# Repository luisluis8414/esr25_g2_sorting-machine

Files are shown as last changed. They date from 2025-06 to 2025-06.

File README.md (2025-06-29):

# esr25_g2_sorting-machine - Medikamenten Sortiermaschine

Dieses Projekt implementiert eine automatisierte Sortiermaschine unter Verwendung des MSP430FR2355. Das System wurde entwickelt, um Objekte (Medikamente) basierend auf ihrer Farbe mithilfe eines Farbsensors und einer servogesteuertern Kippplatform zu sortieren.

# Demo

## Sortiervorgang in Aktion
Sortiervorgang Demo

## Ein paar Bilder
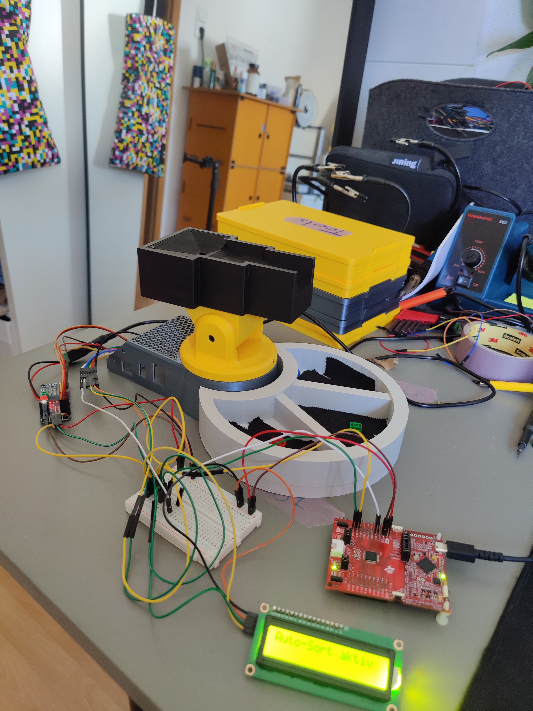
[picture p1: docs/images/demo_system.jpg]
Gesamtsystem
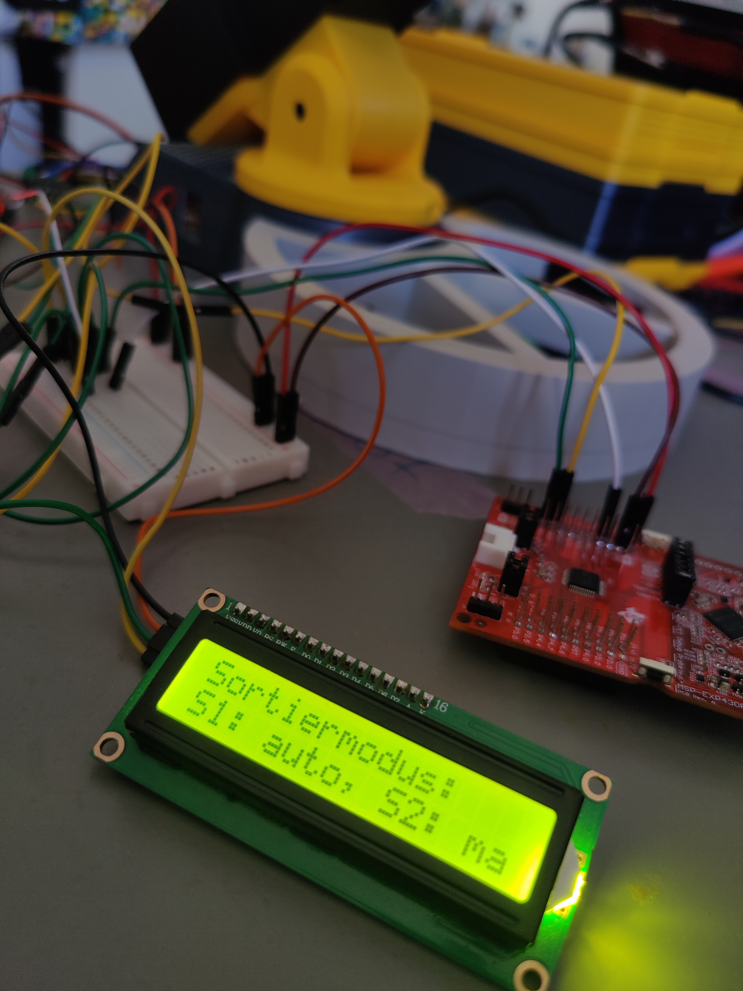
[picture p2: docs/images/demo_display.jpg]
LCD Display
|  |  | Sortiersystem |
|:---:|:---:|:---:|
| *Komplettes System* | *LCD-Display - Hier Auswahl des Sortiermodus* | *Sortierplattform sortiert rote Pille* |

# Systemarchitektur

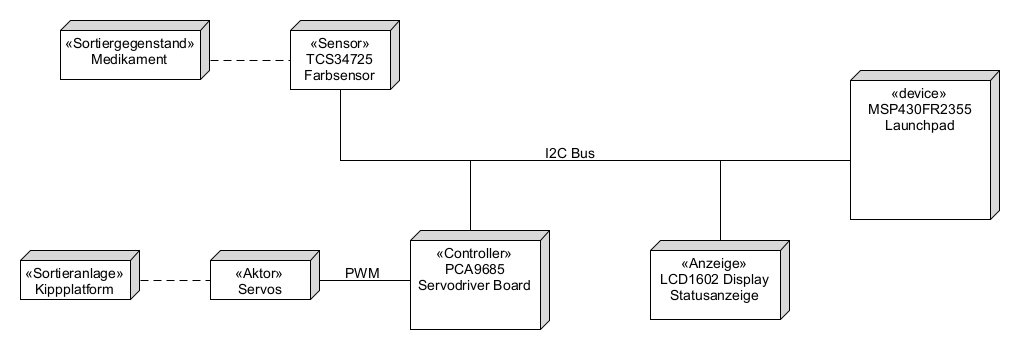
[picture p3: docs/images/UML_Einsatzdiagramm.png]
Systemarchitektur


Das System besteht aus folgenden Hauptkomponenten:

- **MSP430FR2355 Launchpad**: Mikrocontroller
- **TCS34725 Farbsensor**: RGB-Farberkennung zur Objektidentifikation
- **PCA9685 Servotreiber**: PWM-Controller für Servomotoren
- **LCD1602 Display**: Statusanzeige für System-Feedback
- **Servomotoren**: Aktoren für die Sortierplattform

# Hardware-Implementierung

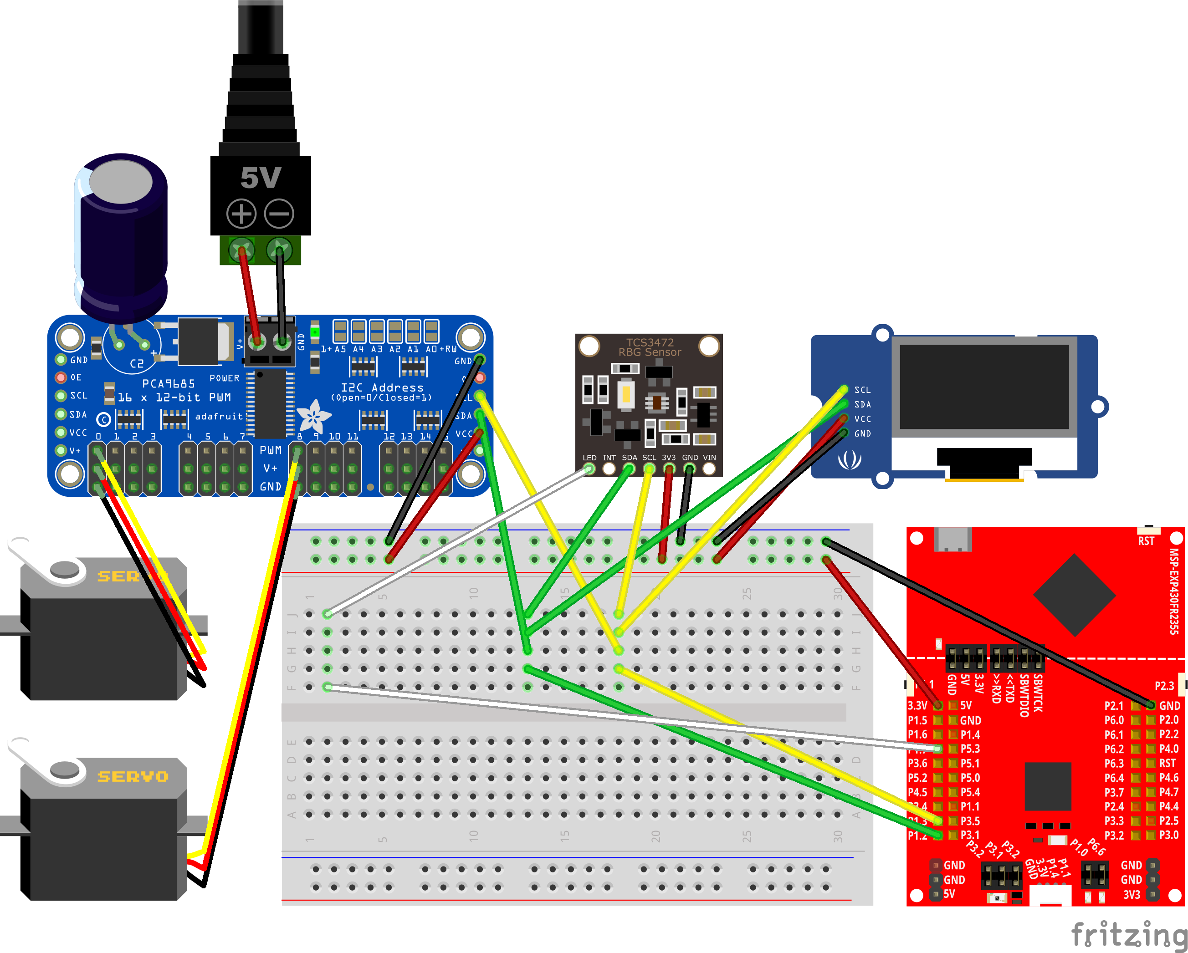
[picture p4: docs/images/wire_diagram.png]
Verdrahtungsplan


## Hauptkomponenten und Verbindungen

- **I2C-Bus-Kommunikation**:
  - Verbindet den Farbsensor (TCS34725)
  - Steuert den Servotreiber (PCA9685)
  - Kommuniziert mit dem LCD-Display (LCD1602)
- **Servo-Plattform**: Mechanischer Sortiermechanismus, gesteuert durch Servomotoren
- **Stromversorgung**: 3.3V-Stromverteilung für alle Komponenten, 5V extra Versorgung für die Sevos

# Mikrocontroller-Peripherie

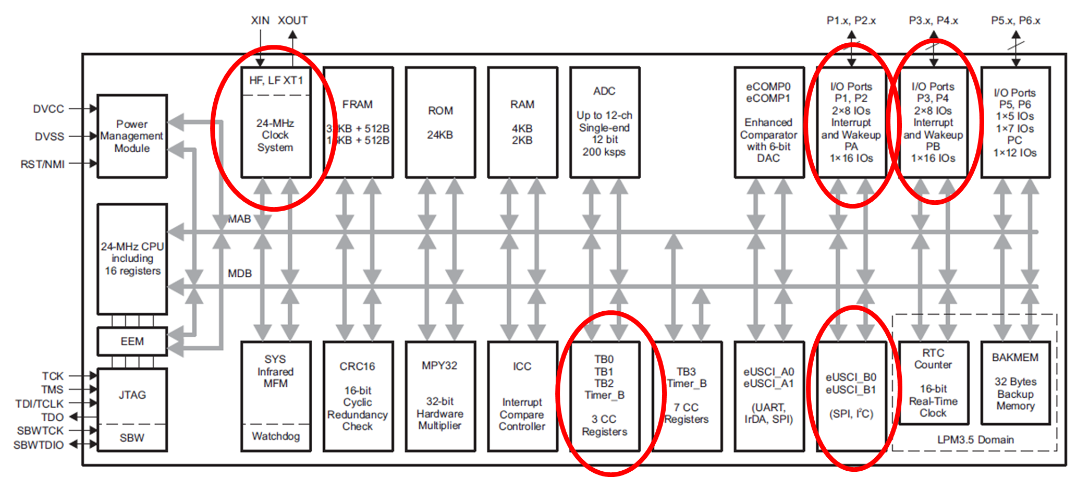
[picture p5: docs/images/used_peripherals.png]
Verwendete Peripherie


Der MSP430FR2355 nutzt folgende wichtige Peripheriekomponenten:

- **I2C-Schnittstelle**: Für die Kommunikation mit TCS, PCA und LCD
- **Timer-Module**: Für Timer, Systemtick und button debouncing
- **GPIO-Ports**: Für allgemeine Ein-/Ausgabesteuerung
- **Taktsystem**: 1MHz Systemtakt

# Projektstruktur

```
esr25_g2_sorting-machine/
├── button/             - Button-Schnittstellenimplementierung
├── I2C/                - I2C-Kommunikationsprotokoll
├── lcd1602_display/    - LCD-Display-Treiber und Manager
├── led/                - LED-Steuerungsimplementierung
├── PCA9685/            - Servotreiber-Controller
├── platform/           - Plattform-Steuerungslogik
├── state_machine/      - Hauptsystem-Zustandsverwaltung
├── TCS34725/           - Farbsensor-Treiber
└── timer/              - Timer-Konfigurationen
```

# Dokumentation generieren

Das Projekt verwendet Doxygen zur Dokumentationsgenerierung. Um die Dokumentation zu erstellen:

1. Stelle sicher, dass [Doxygen](https://www.doxygen.nl/download.html) installiert ist
2. Führe das Script `generate_docs.bat` aus
3. Die generierte Dokumentation ist unter `docs/html/index.html` auffindbar

Das Script wird automatisch:
- Die Doxygen Awesome CSS Theme herunterladen (falls nicht vorhanden)
- Die alte Dokumentation löschen
- Neue Dokumentation generieren
- Die Dokumentation im Browser öffnen

Die Dokumentation enthält:
- Detaillierte API-Beschreibungen
- Funktionsreferenzen
- Architekturdiagramme
- Hardwareverbindungen
- Beispielbilder des Systems

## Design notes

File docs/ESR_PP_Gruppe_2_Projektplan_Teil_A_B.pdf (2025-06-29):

Prof. Dr. rer. biol. hum. Sven Steddin, Medizinisch-Technische Informatik
Hochschule Reutlingen, Alteburgstraße 150, 72762 Reutlingen, www.reutlingen-university.de,
T. +49 (0)7121 271-4011, sven.steddin@reutlingen-university.de

Sortiermaschine mit dem MSP430.

Gruppe
(Bez. aus RELAX)

Gruppenmitglieder (Namen)

ESR__PP_Gruppe_2 Raach, Qunaku, Wehrberger

## Inhalt

Festlegung des bestimmungsgemäßen Gebrauchs (Produktvision /

Nutzungsanforderungen zu NS02: Auslesen des aktuellen Füllzustands der

S2025 – Eingebettete Systeme und Robotik – Projektbeschreibung Vorlage Ver.2 (23.05.2025)

# Aufbau eines Medikamentensortierers

## Teil A (Analysephase): Projektbeschreibung

„Kein Projekt ohne Angabe eines Ziels!“

## Beschreibung des Kontextes der Entwicklung / Motivation

Kontextszenarien
KS01: Sortierung von Medikamenten (Pillen) für Menschen mit Farbblindheit.

Medikamente werden heutzutage immer noch anhand ihrer Farbe unterschieden, insbesondere bei Pillen und Tabletten. Dies erleichtert Patienten sowie Pflegepersonal die schnelle Identifikation und Unterscheidung verschiedener Präparate. Farben dienen oft als visuelle Orientierungshilfe, um Verwechslungen zu vermeiden und die korrekte Einnahme sicherzustellen.

KS02: Sortierung und Zählung von Medikamenten (Pillen) in Apotheken und Pflege

In Pflegeeinrichtungen und Apotheken spielt die manuelle Sortierung und Zählung von Medikamenten eine zentrale Rolle im täglichen Ablauf. Medikamentenbestände müssen regelmäßig überprüft, korrekt zugeordnet und für Patienten oder Kunden bereitgestellt werden. Dabei wird großer Wert auf eine strukturierte Organisation gelegt, um sicherzustellen, dass die richtigen Medikamente zur richtigen Zeit verfügbar sind.

KS02: Verwaltung von Medikamenten

Senioren nehmen oft täglich mehrere Medikamente ein und müssen dabei auf eine strikte Medikamentenverwaltung achten, um eine kontinuierliche Versorgung sicherzustellen. Oft sind Angehörige, Pflegekräfte oder Apotheken unterstützend tätig, um den Überblick über Vorräte und Einnahmezeiten zu erleichtern.

## Festgestellte Mängel (Pain Points)

PP01: Zu bemängeln ist, dass Medikamente oft über ihre Farbe unterschieden werden, was für Menschen mit Farbblindheit ein Risiko von Einnahmefehlern sein kann und oft die Selbstständigkeit einschränkt.

PP02: Zu bemängeln ist, dass Senioren sich oft schwertun, selbst einen Überblick über die Anzahl ihrer übrigen Medikamente zu bewahren.

PP03: Zu bemängeln ist, dass das manuelle Sortieren von Medikamenten in Apotheken und Pflegeeinrichtungen sehr Zeit aufwändig ist.

## Festlegung der Zweckbestimmung des zu entwickelnden Systems

ZB01: Die Entwicklung soll dazu dienen, Medikamente/Pillen automatisch anhand der Farbe zu sortieren. (PP01)

ZB02: Die Entwicklung soll dazu dienen, die Anzahl an unterschiedlichen Pillen zu zählen und wiederzugeben. (PP02)

ZB03: Die Entwicklung soll dazu dienen, Apotheken- und Pflegepersonal das Sortieren und Zählen von Pillen zu vereinfachen. (PP03)

## Festlegung des bestimmungsgemäßen Gebrauchs (Produktvision / Nutzungsszenarien)

NS01: Sortierung von Pillen
Umgesetzte Zweckbestimmungen

ZB01, ZB02, ZB03
Vorbedingungen
1. Das Sortiersystem liegt auf einer stabilen Ebene
2. Die Pillen unterscheiden sich in den Farben Rot, Grün und Blau

Nutzungsvorgang

1. Der Anwender bzw. das Bedienpersonal startet das Sortiersystem und wirft in langsamen Abständen die Pillen einzeln in den Eingang des Sortiersystems.
2. Das Sortiersystem sortiert die Pille innerhalb des Systems und erhöht die auf dem Display angezeigte Menge je Farbe.
3. Der Anwender bzw. das Bedienpersonal führt diesen Vorgang durch, bis alle Pillen sortiert sind

Nachbedingungen

- Die Pillen können aus dem System entnommen werden

NS02: Erfassung der Gesamtanzahl der bislang sortierten Pillen, inklusive farblicher Aufschlüsselung der Stückzahlen.
Umgesetzte Zweckbestimmungen

ZB02

Vorbedingungen

- System ist deaktiviert, und nicht am Sortieren.

Nutzungsvorgang

1. Das Bedienpersonal aktiviert das Füllzustands-Display.
2. Das Display zeigt wie viele Pillen bisher sortiert wurden. Zusätzlich zeigt es jeweils die Anzahl pro Farbe an.
3. Der Anwendende liest den aktuellen Füllzustand der Sortiermaschinen-Behälter aus.

Nachbedingungen

- Display geht in den vorherigen Zustand also, deaktiviert oder in die Anzeige des Displays des Bereitschaftsmodus.

## Stakeholder

Stakeholder | Benutzerrolle
Patienten mit Farbsehstörungen | Person, welche selbständig ihre Medikamente identifizieren und unterscheiden will.
Senioren mit regelmäßiger Medikamentenein- nahme | Person, die ihren Medikamentenbestand leicht kontrollieren will.

Pfegepersonal in
Einrichtungen

Person, die schnell Medikamente Sortieren und eine Übersicht über Vorräte will

Bedienpersonal | Patienten, Senioren und Pflegepersonal

## Festlegung der Nutzungsanforderungen (funktionale Anforderungen)

## Nutzungsanforderungen zu NS01: Sortierung von Pillen

# | Nutzungsanforderung | Definition of Done

NA001 | Als Bedienpersonal der Sortiermaschine möchte ich die Sortierung einer Pille starten können, damit ich nicht aus Versehen eine Pille sortieren lasse oder etwas Falsches darin sortiere. | Es ist eine Eingabefunktion vorhanden, die den Sortierprozess der Sortiermaschine initialisiert.
NA002 | Als Bedienpersonal der Sortiermaschine möchte ich die Möglichkeit haben farbige Pillen (rot, grün oder blau) einzeln hinzuzufügen, damit sie sortiert werden können.

Es ist eine Form von Oberfläche vorhanden, worauf die zu sortierende farbige Pille (rot, blau oder grün) liegen kann, sodass sie sortiert werden kann.

NA003 Als Bedienpersonal der Sortiermaschine möchte ich sehen können, welche Zuordnung passiert ist, um sicherzustellen, dass die Zuordnung korrekt ist.

Es ist eine visuelle Anzeige vorhanden, die dem Bedienpersonal aufzeigt, welche Zuordnung für die Pille erfolgt ist.

NA004 Als Bedienpersonal der Sortiermaschine möchte ich eine eindeutige Stelle erkennen können, an der die Pille zum Sortierprozess eingegeben werden kann, um sie an die richtige Stelle zu legen.

Es besteht eine Eingabefläche für die Pillen an der Sortiermaschine.

NA005 Als Bedienpersonal der Sortiermaschine möchte ich erkennen können, ob die Sortierung gestartet wurde, um zu wissen, wie der Zustand der Sortiermaschine ist.

Es gibt ein visuelles Feedback an das Bedienpersonal bei Beginn des Sortierprozesses.

NA006 Als Bedienpersonal der Sortiermaschine möchte ich die Möglichkeit haben zu sehen, ob ich eine Pille sortieren lassen kann, um zu wissen, wann ich die nächste Pille nachlegen kann.

Es ist eine visuelle Anzeige vorhanden, die dem Bedienpersonal aufzeigt, dass die Sortiermaschine sortierbereit ist.

NA007 Als Bedienpersonal der Sortiermaschine möchte ich die Möglichkeit zu sehen, ob der Prozess der Sortierung beendet ist, um den Sortierungszustand zu kennen.

Es ist eine visuelle Anzeige vorhanden, die dem Bedienpersonal aufzeigt, dass der Sortierprozess beendet wurde.

NA008 Als Bedienpersonal der Sortiermaschine möchte ich, dass für jede Pillenfarbe (rot, grün, blau) ein separater, zugeordneter Behälter vorhanden ist, damit die Pillen nach der Sortierung eindeutig und sauber getrennt gesammelt werden können.

Es sind Behälter am System vorhanden, die das System erreichen kann, um Pillen zu sammeln.

NA009 Als Bedienpersonal der Sortiermaschine möchte ich, dass die erkannte Pille dem farblich passenden Behälter zugeführt wird, damit sie sortiert bleibt.

Es ist ein Mechanismus vorhanden, der, die auf der Oberfläche liegende, Pille in den korrekten Behälter zuführt.

NA0010 Als Bedienpersonal der Sortiermaschine möchte ich, dass das System die Farbe (rot, grün

Es ist ein Mechanismus mit einer Sensorik vorhanden, der rote, blaue oder blau) jeder eingeführten Pille erkennt und zuweist, damit die Pillen unterschieden und sortiert werden können.

und grüne Pillen voneinander unterscheiden und zuweisen kann.

NA0011 Als Bedienpersonal der Sortiermaschine, möchte ich die Sortiermaschine aktivieren können, damit sie nur bei Bedarf läuft.

Es ist eine Eingabefunktion vorhanden, die die Sortiermaschine aktiviert.

## Nutzungsanforderungen zu NS02: Erfassung der Gesamtanzahl der bislang sortierten Pillen, inklusive farblicher Aufschlüsselung der

Stückzahlen.

NA011 Als Bedienpersonal der Sortiermaschine, möchte ich sehen können wie viele Pillen bereits sortiert worden (inklusive der Anzahl pro Farbe) sind, um zu wissen, wie die Verteilung der Pillen ist und wie viele Pillen bisher sortiert worden sind.

Es ist eine visuelle Anzeige vorhanden, die dem Anwender die Gesamtanzahl der bislang sortierten Pillen, inklusive farblicher Aufschlüsselung der Stückzahlen anzeigt.

NA012 Als Bedienpersonal der Sortiermaschine möchte ich die Möglichkeit haben die Zähler, der sortierten Pillen, anzuzeigen, um den Zustand bei Bedarf zu sehen.

Es gibt ein Eingabegerät, dass dem Anwender ermöglicht eine Anzeige des Füllstands zu aktivieren.

NA013 Als Bedienpersonal der Sortiermaschine möchte ich die Möglichkeit haben, den Counter der bisher sortierten Pillen zurückzusetzen.

Es gibt ein Eingabegerät, dass dem Anwender ermöglicht den Counter der Pillen zurückzusetzen.

## Festlegung der Systemanforderungen

## Funktionale Anforderungen

# | Systemanforderung funktional (SAF)

Bestimmungsgröße

Testverfahren

SAF-01 /
NA001

Das System muss ein mechanisches Bedienelement besitzen, um einen Sortierprozess initialisieren zu können.

Betätigung des
Bedienelements

Der Sortierprozess lässt sich über eine Taste starten.

Pass:
Der Sortierprozess wird geeignet gestartet.

SAF-02 /
NA002

Das System muss eine Oberfläche besitzen, auf der eine farbige Pille liegen kann, damit sie sortiert werden kann.

Vorhandensein der
Oberfläche

Auf die Oberfläche wird eine farbige Pille gelegt und ein Sortierprozess wird initialisiert und durchgeführt.

Pass:
Sortierprozess der Pille läuft vollständig und ohne
Beeinträchtigung, durch die Oberfläche ab und Pille liegt vor der Beförderung zum Behälter auf der Oberfläche.

SAF-03 /
NA003

Das System muss eine visuelle Ausgabe/ Display besitzen, um die Zuordnung einer erkannten Pille darzustellen.

Erkannte Farbe | Der Sortierprozess des Systems wird einzeln mit einer roten, blauen und grünen Pille ausgeführt. Pass: Bei jeder Pille wird die jeweils richtige Farbe zu einem geeigneten Zeitpunkt dargestellt.

SAF-04/
NA004

Das System muss eine Eingabefläche für eine farbige Pille besitzen, damit die Sortierung überhaupt stattfinden kann.

Vorhandensein der
Eingabefläche

Es wird eine Pille auf die Oberfläche gelegt.

Pass:
Nach der Auflage der Pille auf die Oberfläche ist ein Sortierprozess startbar.

SAF-05 /
NA005

Das System muss eine visuelle Anzeige besitzen, um darstellen zu können, dass der Sortierungsprozess begonnen hat.

Systemstatus | Es wird ein Sortierprozess nach Auflage einer Pille initialisiert. Pass: Das Display zeigt zu einem geeigneten Zeitpunkt den Beginn der Sortierung an. .

SAF-06 /
NA006

Das System muss eine visuelle Anzeige besitzen, um darstellen zu können, dass der Sortierungsprozess bereit ist.

Systemstatus | Die Sortiermaschine wird in den Bereitschaftsmodus gesetzt. Pass:
a) Nach Aktivierung der
| Sortiermaschine per Tastendruck zeigt Display geeignet an, dass sie bereit ist.
b) Nach erfolgreich beendetem
| Sortierungsprozess der Sortiermaschine zeigt Display geeignet an, dass sie bereit ist.

SAF-07 /
NA007

Das System muss eine visuelle Anzeige besitzen, um darzustellen zu können, ob der Prozess der Sortierung beendet ist.

Systemstatus | Es wird ein Sortierprozess nach Auflage einer Pille initialisiert. Pass: Das Display zeigt zu einem geeigneten Zeitpunkt das Ende der Sortierung an. .

SAF-08/
NA008

Das System muss für jede mögliche Zuordnungsfarbe einen für das System erreichbaren Behälter besitzen, in denen Pillen aufbewahrt werden können, damit nach der Sortierung die Pillen getrennt gesammelt werden können.

Farben | Der Sortierprozess des Systems wird einzeln mit einer roten, blauen und grünen Pille ausgeführt. Pass: Für jede Pille gibt es einen eigenen Behälter und nach jedem Sortierungsprozess ist Pille in entsprechendem Behälter.

SAF-09/
NA009

Das System muss einen Mechanismus besitzen, der eine erkannte Pille automatisch in den zugeordneten Behälter befördert, um die Sortierung zu persistieren.

Farbzuordnung | Der Sortierprozess des Systems wird einzeln mit einer roten, blauen und grünen Pille ausgeführt. Pass: Jede Pille landet in ihrem geeigneten Behälter, sobald die Erkennung und Zuweisung der Pille erfolgt ist.

SAF-010/
NA0010

Das System muss einen Mechanismus besitzen, die Farben …

a) Rot,
b) Blau oder
c) Grün
einer Pille zu unterscheiden und sie entsprechend zuzuweisen, um die Sortierungsfähigkeit zu gewährleisten.

Farbdaten des Sensors Der Sortierprozess des Systems wird einzeln mit einer roten, blauen und grünen Pille ausgeführt. Pass: Für jede Pille wird die geeignete Farbe erkannt und zugewiesen und Display zeigt geeignete Farbe an und Pille landet in richtigem Behälter.

SAF-011/
NA0011

Das System muss ein mechanisches Bedienelement besitzen, um die Sortiermaschine zu aktivieren.

Betätigung des
Bedienelements

Der Sortiermaschine lässt sich über eine Taste starten.

Pass:
Die Sortiermaschine startet und geht in einen geeigneten
Bereitschaftsmodus.

SAF-012/
NA011

Das System muss ein Display besitzen, dass die aktuellen Zähler der Sortiermaschine darstellt, um dem Bedienpersonal die Anzahl der bisher sortierten Pillen anzuzeigen.

Anzahl der Pillen | Das Display der Sortiermaschine wird per Tastendruck aktiviert.
| Pass: Das Display zeigt die korrekten Zähler der sortierten Pillen der Sortiermaschine an.

SAF-013/
NA012

Das System muss ein mechanisches Bedienelement besitzen, um das Füllstand-Display aktivieren zu können.

Betätigung des
Bedienelements

Das Display lässt sich über eine Taste starten.

Pass:
Das Display geht an und zeigt Informationen an.

SAF-014/
NA011

Das System muss in der Lage sein, die bisher sortierten Pillen zu zählen, um die Anzahl der bisher sortierten Pillen zu erfassen (Gesamtzahl und Anzahl pro Farbe).

Pille | Der Sortierprozess des Systems wird einzeln mit einer roten, blauen und grünen Pille ausgeführt. Pass: Für jede Pillenfarbe wurde eine Pille gezählt und angezeigt. Und nach jedem Sortierungsprozess ist die Gesamtzahl der Pillen, um eins inkrementiert.

SAF-015/
NA011

Das System muss ein mechanisches Bedienelement besitzen, um die Zähler der bisher sortierten Pillen zurückzusetzen, um die Anzahl von Neuem erfassen zu können.

Betätigung des Bedienelements | Der Sortierprozess des Systems wird einzeln mit einer roten, blauen und grünen Pille ausgeführt. Pass: Nach dem Betätigen des mechanischen Bedienelements zeigen die Zähler bei der Gesamtzahl und Zahl pro Farbe jeweils null an, nachdem die Anzeige dafür aktiviert wurde.

## Nicht funktionale Anforderungen

# Systemanforderung nicht funktional (NFA)

Testverfahren
(Definition of Done)

NFA-01

Das System muss mit dem Launchpad MSP430FR2355 umgesetzt werden

Sichtkontrolle: Prüfung der Produktbezeichnung auf der Systemplatine

NFA-02

Das System muss mit dem CCS, Version 12.0 oder höher erstellt werden

Kontrolle der Version des Entwicklungssystems auf dem Entwicklungsrechner:
a) Version muss der Anforderung entsprechen
b) Programm muss sich fehlerfrei übersetzen und auf das Zielsystem übertragen lassen
NFA-03

Das System muss ein Hauptprogramm besitzen, welches ein state machine design implementiert (Mealy Automat): Beispiel wird in der Vorlesung gezeigt.

Code review

NFA-04

Das System darf, von kleinen Ausnahmen abgesehen, kein busy waiting betreiben, d.h. es müssen die Low Power Modes des Prozessors genutzt werden. Diese Anforderung hat oberste Priorität!

Review der main loop des Programmes

NFA-100

Das System muss mit Hilfe von Doxygen dokumentiert werden

Aufruf des zum Projekt gehörenden Doxygen Scripts zur Erzeugung der vollständigen Dokumentation im HTML Format -- > Es muss ein vollständig über Doxygen generiertes manual erzeugt werden.
NFA-101

Die Software und die Dokumentation müssen unter Versionskontrolle stehen. Hierfür ist GIT einzusetzen.

Kontrolle der Struktur des zugehörigen Repository über den TortoiseGIT Repository Explorer oder über ein vergleichbares Tool zur Inspektion des Repository

NFA-102

Alle Dokumente zur Dokumentation der Software sollen zusammen mit dem Source Code im Stammverzeichnis des CCS Projekts im Ordner Docs abgelegt werden. Es wird eine Projektvorlage zur Verfügung gestellt, die diese Struktur bereits besitzt.

Kontrolle der Struktur des Docs-Verzeichnisses im Projektverzeichnis:

NFA-103

Das System muss in einer 3 Minuten Demo vollständig präsentierbar sein

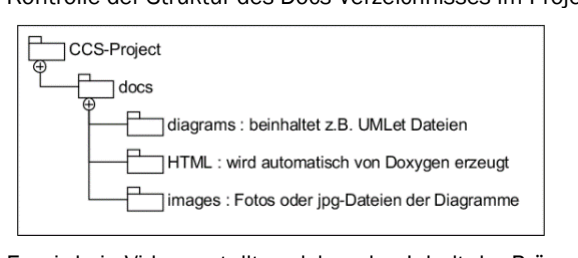
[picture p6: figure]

Es wird ein Video erstellt, welches den Inhalt der Präsentation wiedergibt und das nachweislich nicht länger als 3 Minuten dauert.

NFA-104

Das System muss über eine 3V Batterie im stand-alone Modus betrieben werden können (, getrennt von den Servomotoren).

System wird mit 3V Lithium Knopfzelle verbunden. ICD-Bereich wird über Jumper als Verbraucher vom MC-Bereich des Launchpads getrennt, damit der Verbrauch des Systems möglichst gering ist. System muss sich starten lassen.

NFA-105

Die Sortiermaschine muss nach der Aktivierung oder einer Sortierung nach 30 Sekunden automatisch beendet werden, so dass die Messsensorik und das Display möglichst wenig Strom verbrauchen.

Die Versorgungsspannung an der Sensorik und am Display muss nach Ablauf der Messdauer abgeschaltet sein.

NFA-106

Der Sortierprozess muss nach spätestens fünf Sekunden terminiert sein, so dass das Bedienpersonal möglichst schnell Pillen sortieren lassen kann.

Sortierungsprozess der Sortiermaschine muss nach Ablauf der Messdauer fertiggestellt sein und Sortiermaschine muss im Bereitschaftsmodus sein.

NFA-106

Das Display der Sortiermaschine muss nach der Aktivierung (per Aktivierung der Sortiermaschine oder per Aktivierung des Displays) oder einer Sortierung nach 30 Sekunden automatisch beendet werden, so dass das Display möglichst wenig Strom verbraucht.

Die Versorgungsspannung am Display muss nach Ablauf der Messdauer abgeschaltet sein.

NFA-107

Das Display der Sortiermaschine muss fünf Sekunden nach der Aktivierung ausgehen, falls es nur aktiviert wurde, um die Gesamtanzahl der bislang sortierten Pillen, inklusive farblicher
Aufschlüsselung der Stückzahlen anzuzeigen. Das soll getan werden, so dass das Display möglichst wenig Strom verbraucht.

Die Versorgungsspannung am Display muss nach Ablauf der Messdauer abgeschaltet sein.

## Zugesicherte Leistungsmerkmale

# | Zugesichertes

| Leistungsmerkmal (ZLM)

Bestimmungsgröße

Testverfahren
(Definition of Done)

ZGL-01 Rutschfeste Auflageoberfläche für eine Pillen.

Material | Die auf der Auflageoberfläche aufliegende
Pille muss bei einer waagrechten Fläche auf der Stelle liegen bleiben.

ZGL-02 Energieversorgung:
Batteriebetriebenes System

Versorgungsspannung:

Betrieb muss bei 2,6V
… 3V Versorgungsspannung möglich sein

Das System muss bei 2,6 V und bei 3V Versorgungsspannung funktionstüchtig sein.

ZGL-03 Batterielebensdauer: Bisher unklar

Durchschnittliche
Stromaufnahme des
Systems während der
Sortierung: Bisher
unklar

Bisher unklar

ZGL-04 Betrieb bei normalen Raumumgebungsbedingungen möglich: Temperatur: 20°C +/-10°C Feuchte: 60% +/- 20%

Temperatur und
Feuchte

System muss bei normalen
Raumbedingungen (20°C / 60% Feuchte) funktionstüchtig sein. Auf eine Prüfung der Grenzwerte wird verzichtet, da bei den angegebenen Werten keine Probleme zu erwarten sind.

ZGL-05 Sortierung ist mit einer >= 95% Wahrscheinlichkeit erfolgreich. (unklar)

Farbe der eingelegten
Pille

Farbsensor-Funktionalität mit Unit-Test gewährleisten.

System muss bei 100 eingegebenen in möglichst zufälliger Reihenfolge mindestens 95 Pillen richtig sortieren.

ZGL-06 Sortierungsprozess erfolgt in <= 5 Sekunden (unklar)

Pille | System muss bei z.B. 100 eingegebenen
Pillen unter 5 Sekunden bei allen Sortierungen sein.

## Teil B: Designphase

## Blackbox Betrachtung: Blockdiagramm

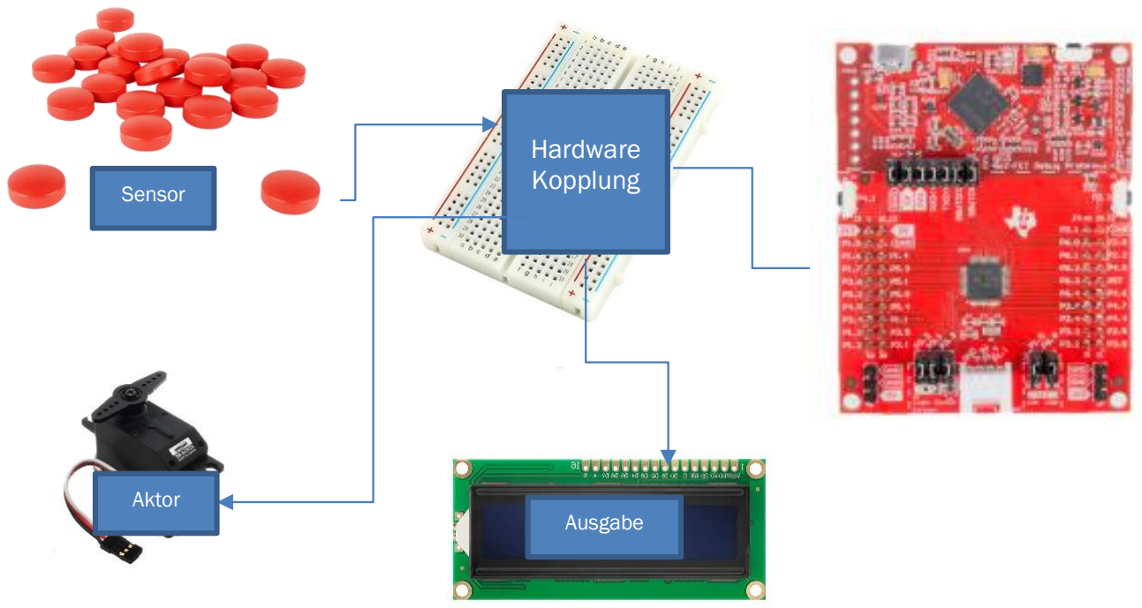
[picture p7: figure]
Hardware Kopplung Sensor; Aktor; Ausgabe

## Systemarchitektur

## Systemdesign: UML Einsatzdiagramm

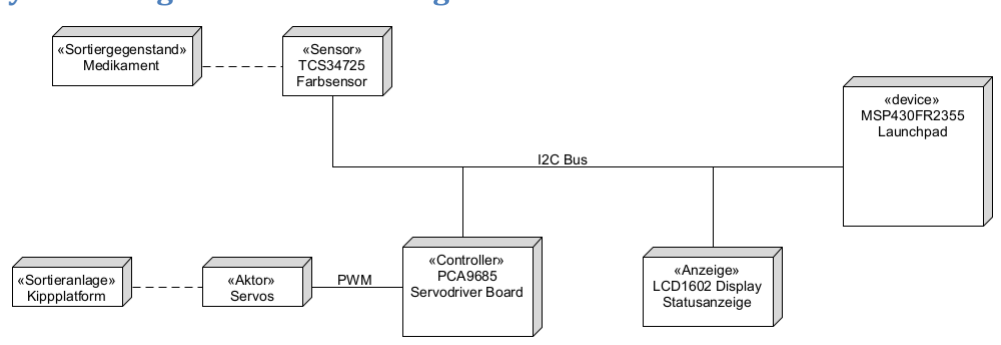
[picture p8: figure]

## Hardware-Design

Erforderliche Sensoren (Input)
# | Sensorbezeichnung | zu erfassende Parameter

Funktion

1

TCS34725 RGB Farb Sensor | RGB-Werte | Der Sensor misst die Farbkomponenten des einfallenden Lichts mit Hilfe integrierter Farbfilter und eines ADCs. Die digitalisierten R, G, B und Clear-Werte werden über den I²C- Bus bereitgestellt. Eine interne LED ermöglicht gleichmäßige Ausleuchtung des Objekts (z. B. Pille)
2 | Taster
Launchpad Taster S2: P2.3 | | Display mit Füllstand einschalten
3 | Taster
Launchpad Taster S1: P4.1

System einschalten

4 | Taster Reset: fest verdrahtet | - | Reset des Systems

Erforderliche Aktoren (Output)
# | Sensorbezeichnung | Ausgabegröße | Zweck

1 | PCA9685/ 2x Servos | PWM | Ansteuerung der Sortiermechanik (Plattformpositionen)
2 | LCD1602 Display mit dem PCF8574A Modul | Textausgabe | Anzeige von Farbwerten, Zuordnung, Counter o. ä.
3 | LED1 (rot) MSP430 Launchpad | On / Off | Zustandsanzeige

Erforderliche Schnittstellen (Kommunikation)
# | Schnittstelle | Betriebsparameter | Zweck

1 | I²C | Anschluss LCD1602,
| | TCS34725 Farbsensor,
| | PCA9685 Servodriver Board

Übermittlung der Steuerbefehle und der Daten die für das Display, Farbsensor und Servodriverboard benötigt werden.

Festlegung der verwendeten Peripheral Blocks

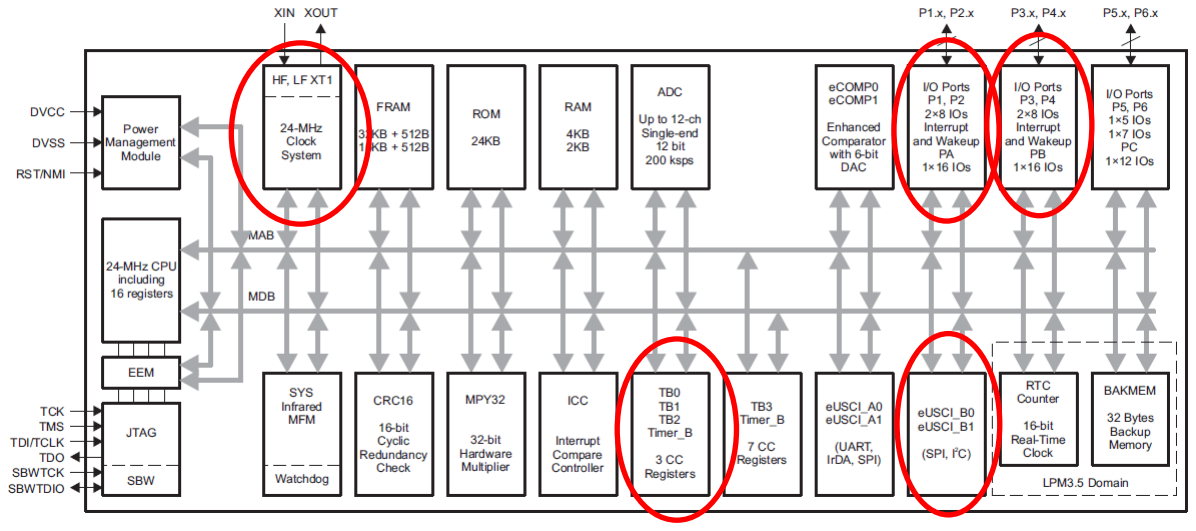
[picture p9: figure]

Block | Einsatzzweck
24 MHz Clock System | Bereitstellung MClk und SMClk (ca. 1 MHz) und AClk, synchronisiert mit 32768 Hz Uhrenquarz
P1 | P1.0: LED1, P1.2: SDA, P1.3: SCL, P1.4: INT (Farbsensor), P1.1: LED (Farbsensor)
P2 | P2.3: Taster S2
P4 | P4.1: Taster S1
Timer0_B3 | Zeitsteuerung der state machine
eUSCI_B0 | I²C-Kommunikation mit Display, Farbsensor und Servodriverboard

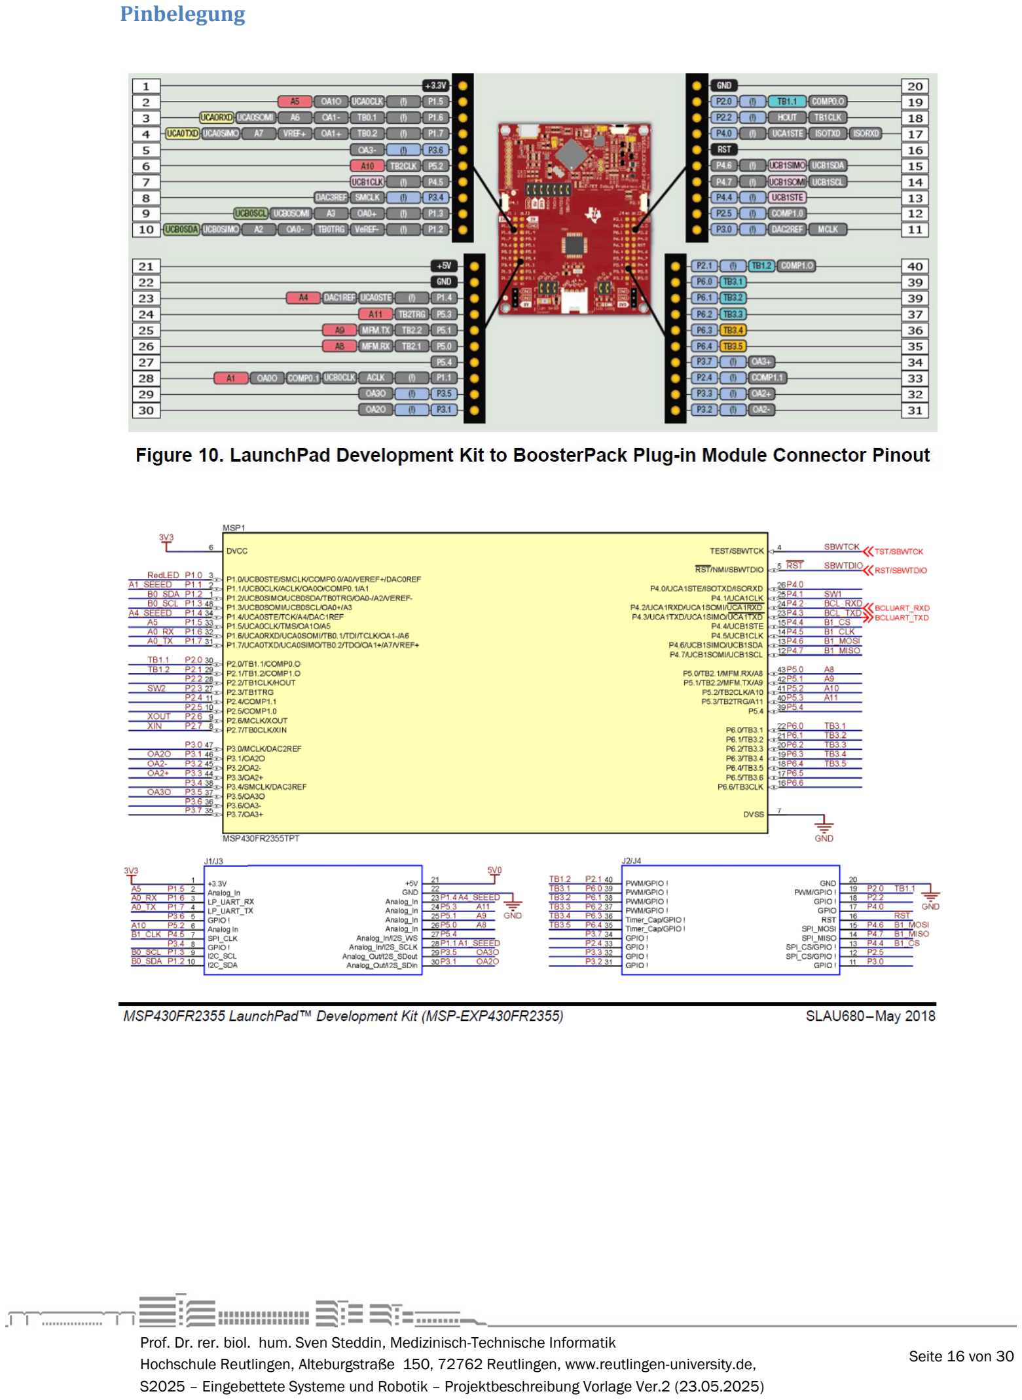
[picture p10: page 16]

Pinbelegung

Pin | Peripherie-block | Pin Name | IC-Pin | LP-Pin | Signal | Zweck
1 | Spannungsver-sorgung | DVCC | | | 3,3V | I²C Anschluss Versorgungsspannung

2
3
4
5
6
7
8
9 | eUSCI_B0 | P1.3 | 48 | 9 | SCL | I²C-Clockleitung
10 | eUSCI_B0 | P1.2 | 1 | 10 | SDA | I²C-Datenleitung
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
20 | Masse | GND | | 20 | - | I²C Anschluss Masseverbindung

21
22
23 | PORT 1 | P1.4 | 34 | 23 | LED | Ansteuerung LED TCS3472
24
25
26
27
28 | PORT 1 | P1.1 | 2 | 28 | INT | Interruptleitung TCS3472
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
Blockschaltbild / Verdrahtungsplan

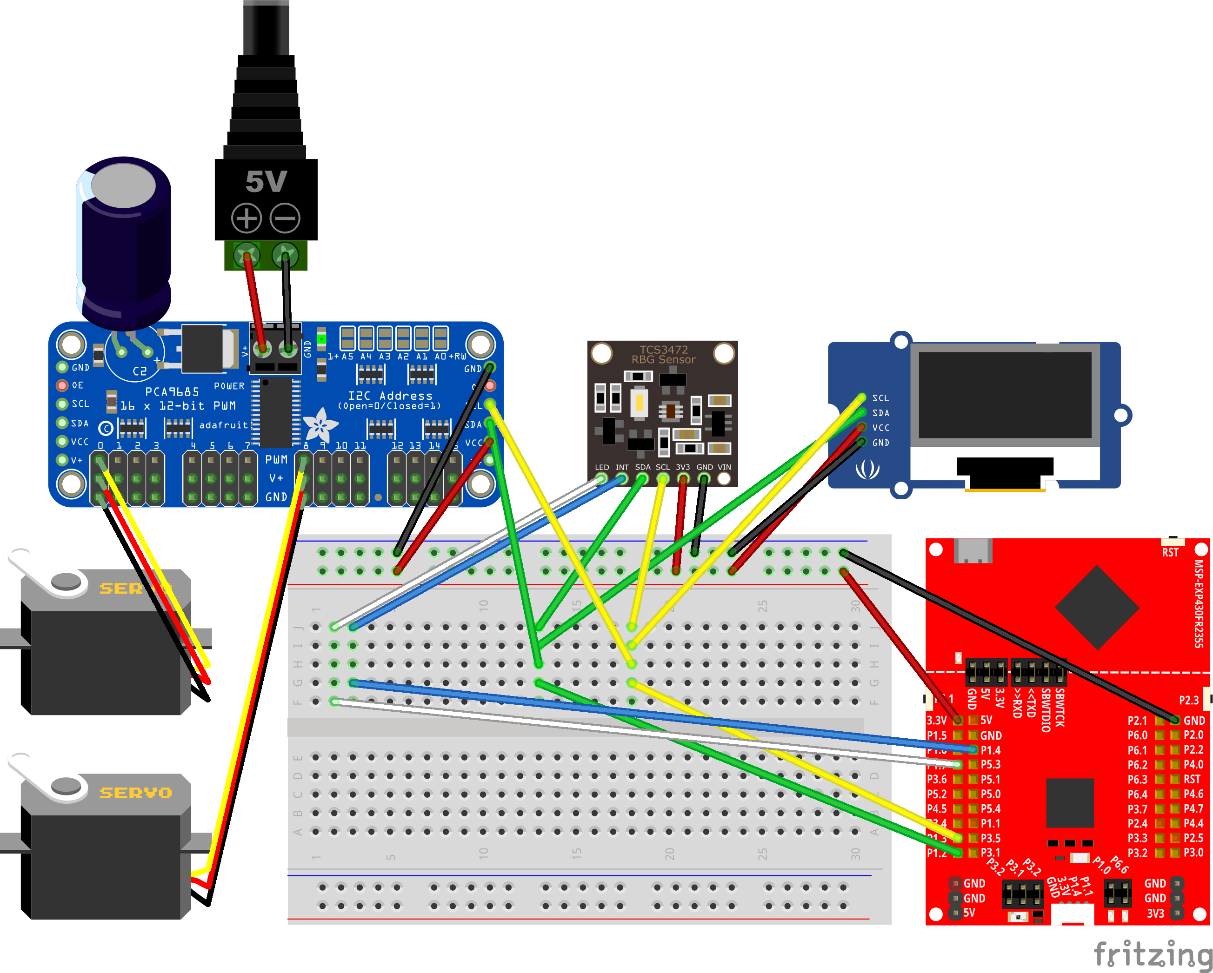
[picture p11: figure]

## Aufwandsschätzung

Peripheral | Function-points | Einsatzzweck
TCS34725 | 4 | Erfassung der Farbe / Lichtschranke
PCA9685/ 2 Servos | 3 | Steuerung der Servos / Kippplattform
LCD1602/ PCF8574A | 4 | Textanzeige, Zähler der sortierten Pillen,
S1/S2 | 2 | System aufwecken, Modus wählen, Start der Messung
LED1 rot/ LED grün | 2 | Statusanzeige
Summe FPs | 15

## Teil C – Implementierung / Umsetzung

## Software-Design

Softwarearchitektur: Use Case Diagramm(e)
[Bla: Umsetzung der Nutzungsszenarien aus Sicht des Systems: welche Funktionen bietet das System an, um die beschriebenen user stories umsetzen zu können? Zu einem Übersichtsdiagramm zugehörig können noch <<includes>> und <<extends>> Beziehungen definiert werden.]

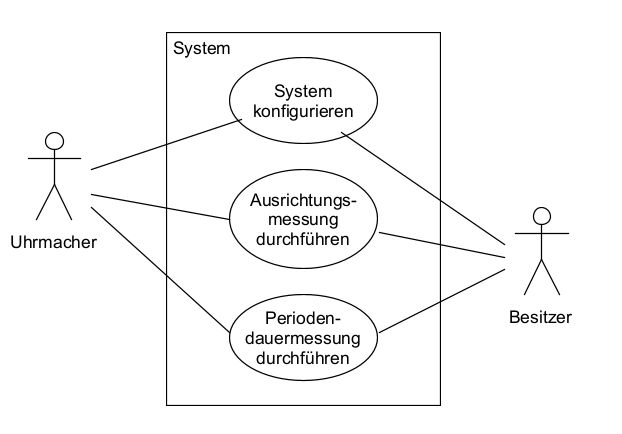
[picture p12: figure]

Softwarearchitektur: Strukturdiagramm
[Bla: Das Softwarestrukturdiagramm zeigt die Dekomposition der Software Komponenten. Hierbei ist darauf zu achten, dass der HAL so ausgelegt wird, dass das API (Festlegung der nach außen sichtbaren Daten und Funktionen) keine Abhängigkeiten zur Applikationsebene besitzt und daher die Treiberfunktionen in jeder beliebigen Applikation verwendbar sind.]

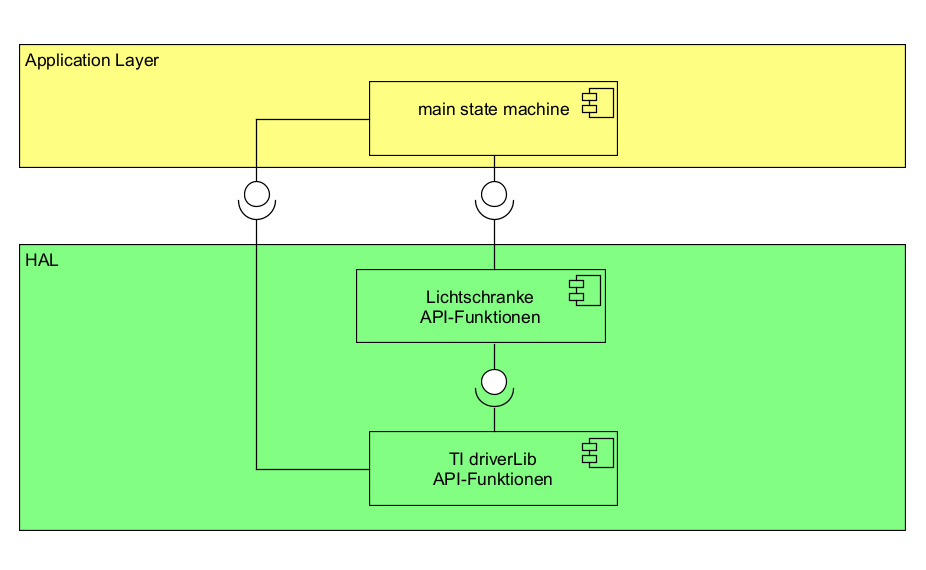
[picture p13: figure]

Aktivitätsdiagramm(e) /state Diagramme
[Bla: Darstellung des Aufbaus der mainloop und der wichtigen ISRs]

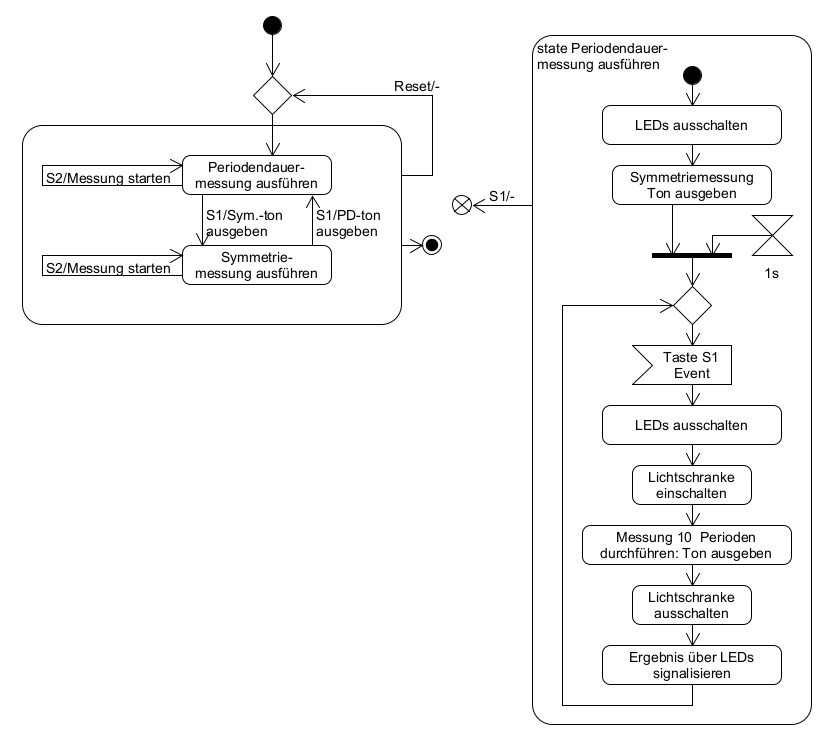
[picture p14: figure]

Abbildung 1 : links - state diagram; rechts: activity diagram

Activity Diagramm für state Symmetriemessung ausführen wie bei state Periodendauermessung ausführen; die beiden States unterscheiden sich nur bzgl. des Algorithmus‘ zur Ergebnisberechnung.

## Softwareanforderungen

[Bla: Jede Systemanforderung muss in mindestens einer Softwareanforderung berücksichtigt werden]

Entfällt im Rahmen des embedded Projekts … ☺

## Softwareentwicklungsplan

Release | Beschreibung der Funktionalität / des Ziels | geplanter
| | Zeitpunkt der
| | Fertigstellung
0.1 | Implementierung der API für die RGB-Farberkennung
- Unterscheidung von Farben rot, grün und blau
| Implementierung der API zur Servoansteuerung
- Rotation der Servos von 0 bis 180 Grad
| Implementierung der Textanzeige auf LCD Display
| - | 16.06
0.2 | Implementierung der on/off Steuerung der Lichtschranke
- Zeitliches An-/Ausschalten des Sensors

[bla]

0.3 | Implementierung Programmlogik
- Definition des Programmablaufs
- Implementierung der main state machine
1.0 | Optimierung und Reifmachung für Deployment | [bla]

## Konfigurationsmanagementplan

- Die Versionsverwaltung erfolgt mittels EGIT über das CCS
- Es gibt einen master branch, der mit einem zentralen Repository abgeglichen wird
- Lokale Entwicklungen werden auf branches im lokalen Repository durchgeführt. Die geprüften Module werden auf den master-Branch überspielt. Dieser wird mit
| dem zentralen Repository abgeglichen.
- Jedes Teammitglied soll vor der Ausführung einer Push-Operation die durchgeführten Änderungen mit den anderen Teammitgliedern besprechen, so
| dass eine gemeinsame Freigabe erfolgen kann.

## Projektstrukturplan

Diagramm
Entfällt im Rahmen des embedded Projekts … ☺

Arbeitspaketbeschreibung
Entfällt im Rahmen des embedded Projekts … ☺

## Projektablaufplan (Gantt)

[ca. 10 Arbeitspakete; Meilensteine und Anordnungsbeziehungen nicht vergessen. Erstellung z.B. mit Visio]

Entfällt im Rahmen des embedded Projekts … ☺

Über Projektbeschreibung bereits vorgegeben

[Bitte beachten: Die Implementierungsphase wird sinnvollerweise mit parallelen Vorgängen durchlaufen, d.h. dass z.B. die sample-Programme zur Anbindung der Sensoren zeitgleich von unterschiedlichen Teammitgliedern erstellt werden, bevor dann die Integration durchgeführt wird. Hierbei ist allerdings darauf zu achten, dass das Projekt so aufgebaut wird, dass das Fehlen eines einzelnen Moduls nicht das gesamte Projekt zu Fall bringt. ]

## Teil D - Produktvalidierung

## Abbildung des aufgebauten Gesamtsystems

[Foto(s) des Gesamtsystems hier einfügen]

## Nachweis der Umsetzung der Nutzungsszenarien

Nachweis, dass die für die user stories vereinbarten Abnahmekriterien erfüllt sind

NS01: Kalibrierung der Kuckucksuhr

NS02: Ausrichtung der Kuckucksuhr

NS03: Wechsel zwischen unterschiedlichen Messmodi

## Nachweis der Umsetzung der Nichtfunktionalen Anforderungen

NFA-01

NFA-02

NFA-03

NFA-04

NFA-100

NFA-101

NFA-102

NFA-103

NFA-104

NFA-105

## Nachweis der Erfüllung der Zugesicherten Leistungsmerkmale

ZGL-01

ZGL-02

ZGL-03

ZGL-04

# Anhang

## Links

## Link zum Code Repository

[bitte hier den Vollständigen Link auf das Gitlab Repo angeben]

## Literatur

[Application notes, Zeitschriftenartikel, Buchartikel, Internetquellen]

[1] Datenblatt zu Lichtschranke TCRT5000 (Zugriff: 2019-05-26) https://www.vishay.com/docs/83760/tcrt5000.pdf
[2] Datenblatt zu Arduino Sensorboard (TCRT5000 IR Barrier Line Track sensor Infrared Reflective Photoelectric Switch)
[4] MSP430FR2x55 family user’s manual
[5] MSP430FR235 datasheet

## Bezugsquellen

## Hardware / Sensoren / Aktoren

Komponente | Bezugsquelle
TCRT5000 IR Sensorboard | https://eckstein-shop.de/TCRT5000-IR-Barrier-Line-Track-sensor- Infrared-Reflective-Photoelectric-Switch (https://eckstein-shop.de/TCRT5000-IR-Barrier-Line-Track-sensor-Infrared-Reflective-Photoelectric-Switch)
| Preis: 2,95€ (Zugriff: 2019-05-25)
… | …

## Software Tools

Komponente Bezugsquelle

UMLet Ver.
14.3.0

https://www.umlet.com/

(Zugriff: 2019-06-01)

## Review des Projektes

## Aufgetretene Probleme

[Bla: Liste]

## Verbesserungsvorschläge für kommende Projekte

[Bla: Liste]

## Entwicklungsprotokolle

[Hier können Notizen zu den einzelnen Zwischenabschnitten hinterlegt werden, z.B. Messergebnisse, Screenshots, Berechnungen, Fotos – alles, was später ggf. für die Nachvollziehbarkeit der Ergebnisse verwendet werden kann.]

## Version 01

Vorbetrachtung;

Aus dem Datenblatt der Lichtschranke lässt sich entnehmen, dass das Signal am Ausgang DD von H auf L geht, sobald ein reflektierender Gegenstand in den Strahlengang kommt. Dies wird mit Hilfe eines Multimeters oder eines Oszilloskops validiert.

Es ergeben sich folgende Softwareanforderungen:

➔ Das System soll auf die fallende Flanke reagieren

➔ Das System soll bei jedem zweiten Interrupt den Zähler auslesen

➔ Der Zähler soll über den SMClk getaktet werden

➔ Der SMClk soll über den genauen Uhrenquarz synchronisiert werden

➔ Der Zähler soll im Continuous Mode betrieben werden und 16 Bit breit sein

Suche nach einem Beispielprojekt für die DriverLib: Nicht verfügbar

Suche nach Beispiel auf Registerebene: msp430fr235x_tb0_capture.c

Somit: Erstes Testprogramm soll auf der Basis von msp430fr235x_tb0_capture.c erstellt werden.

Konfigurationsmanagment:

Die Schrittweise zu erstellenden Projekte werden in das lokale GIT Repository eingestellt.

Die letzte Iteration des Programmes wird in das zentrale Repository übertragen.

## Iteration 1:

Verwendung des Beispielprogramms in Originalfassung

Vorbereitung Hardware:
Der Sensor muss ca. in der Mitte des Pendelweges der Uhr Installiert werden.

Die Empfindlichkeitsschwelle des Sensors muss so eingestellt werden, dass der Pegelwechsel auf L nur dann stattfindet, wenn das Pendel tatsächlich am Sensor vorbeiläuft. Die Untersuchung des Schaltsignals ergibt, dass beim Schalten zumeist keine steile Flanke auftritt, sondern ein Prellen zu beobachten ist. Die Periode des Prellens liegt bei ca. 13µs, die Gesamtdauer des Prellvorgangs dauert, wie oben gezeigt, ca. 250µs. Dies ist jedoch von einer Reihe von Faktoren abhängig. Das Prellen wird reduziert, wenn sich auf dem Pendel eine gut reflektierende und ebene Marke befindet. Dieses Prellen muss per Software kompensiert werden, um einen eindeutigen Zeitpunkt für den Durchlauf des Pendels bestimmen zu können.

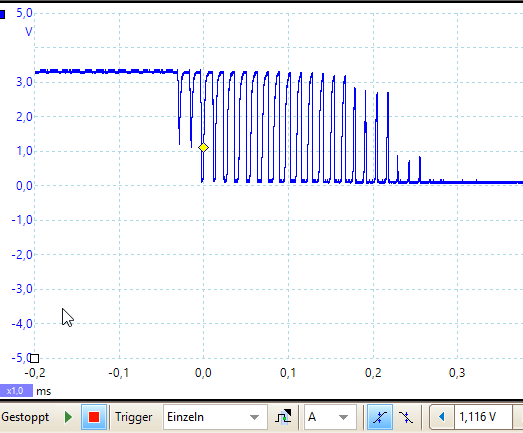
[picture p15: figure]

Insgesamt ergibt sich beim Durchlauf des Pendels ein Schaltimpuls mit einer Dauer, die von der Pendelgeschwindigkeit abhängt und entweder rechnerisch abgeschätzt oder empirisch bestimmt werden kann. Die nachfolgende Abbildung liefert ein Beispiel:

Auf der Rückseite des Pendels kann ein reflektierendes Material angebracht werden, um die Güte des Signals zu optimieren.

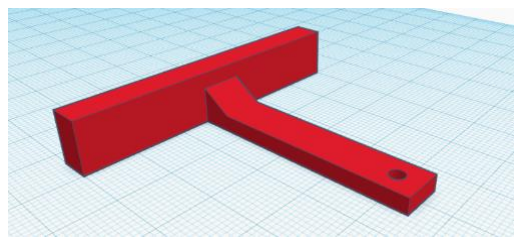
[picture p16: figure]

Um die Messung durchführen zu können, muss der
Sensor am Uhrengehäuse angebracht werden. Hierzu wird mit einem 3-D Drucker eine kleine Halterung erstellt. Die Halterung kann jedoch auch auf andere Weise hergestellt werden.

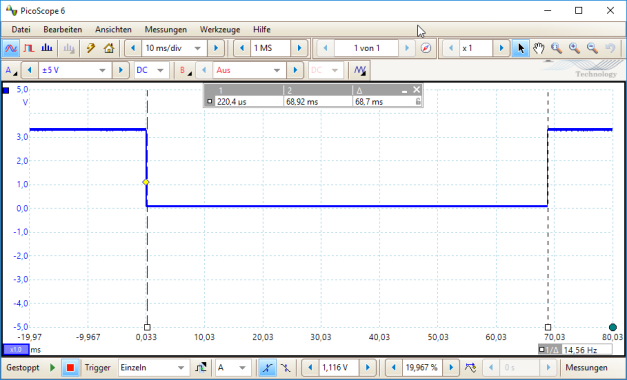
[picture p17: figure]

## Software

Im Beispielprogramm wird Timer B0 und CCIB als Triggereingang verwendet, dieser Input wird aber nicht nach außen geführt. Also muss ein Pin gesucht werden, der über eine der Pfostenleisten zugänglich ist und möglichst keine weitere „secondary function“ besitzt, die ebenfalls eingesetzt werden müsste.

Anschluss des Sensorsignals an Pin 26:

Begründung:

Keine Doppelbelegung z.B. mit UART, d.h. bei Verwendung dieses Pins sollten keine Konflikte auftreten.

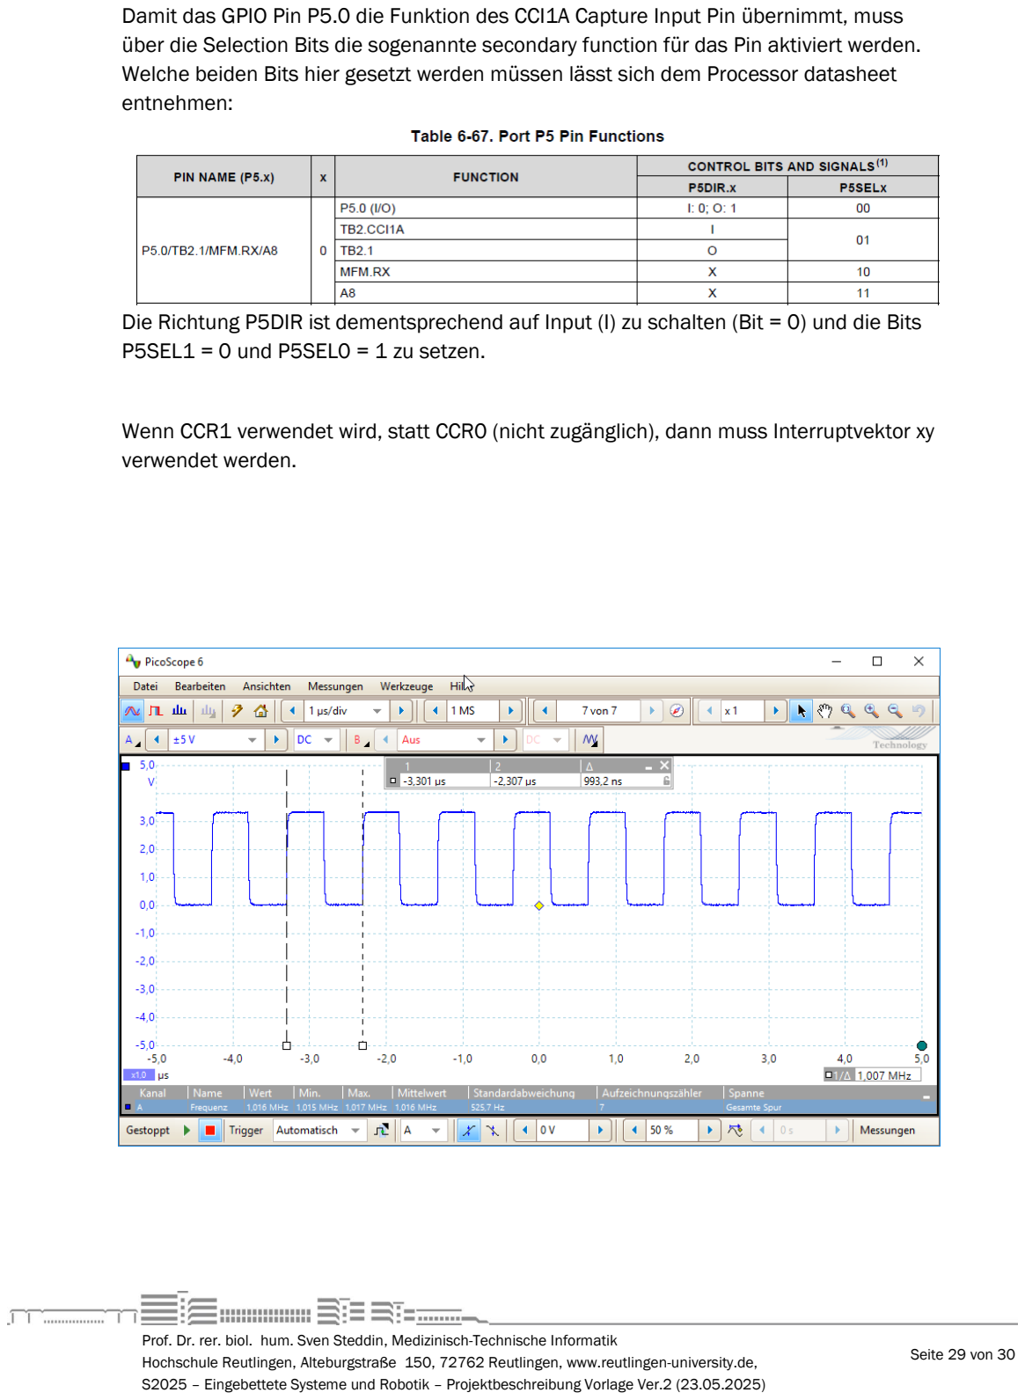
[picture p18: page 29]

Damit das GPIO Pin P5.0 die Funktion des CCI1A Capture Input Pin übernimmt, muss über die Selection Bits die sogenannte secondary function für das Pin aktiviert werden. Welche beiden Bits hier gesetzt werden müssen lässt sich dem Processor datasheet entnehmen:

Die Richtung P5DIR ist dementsprechend auf Input (I) zu schalten (Bit = 0) und die Bits P5SEL1 = 0 und P5SEL0 = 1 zu setzen.

Wenn CCR1 verwendet wird, statt CCR0 (nicht zugänglich), dann muss Interruptvektor xy verwendet werden.

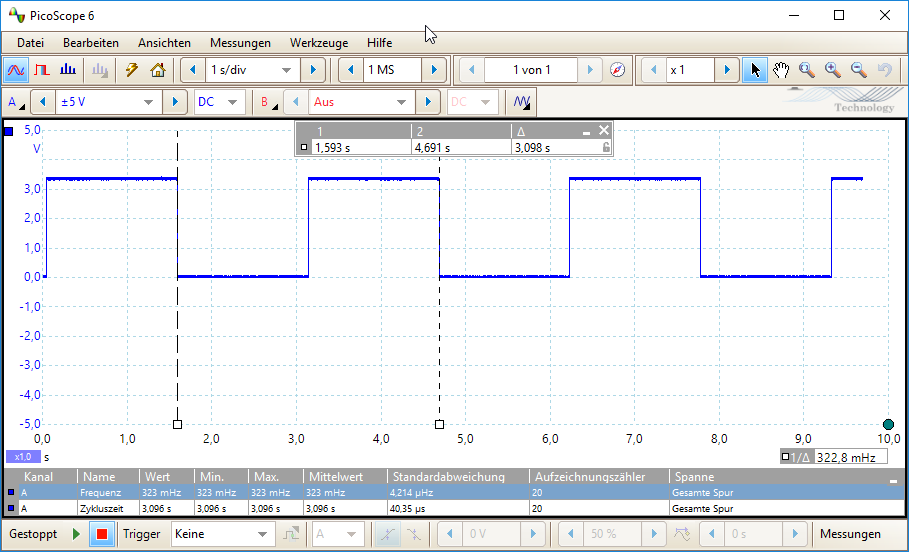
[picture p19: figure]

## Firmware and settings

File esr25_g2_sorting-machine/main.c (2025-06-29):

/* ========================================================================== */
/* main.c                                                                       */
/* ========================================================================== */
/**
 * @file      main.c
 * @author    wehrberger, raach, qunaku
 * @date      22.05.2025
 *
 * @brief     Hauptprogramm der Sortieranlage.
 *
 * Dieses Modul implementiert die Hauptfunktionalität der Sortieranlage:
 *   - Initialisierung aller Hardwaremodule
 *   - Event basierte main loop
 *   - Watchdog und GPIO Konfiguration
 */

#include <msp430.h>
#include <stdint.h>
#include <stdbool.h>

#include "PCA9685/PCA9685.h"
#include "button/button.h"
#include "platform/platform.h"
#include "I2C/I2C.h"
#include "timer/timer.h"
#include "TCS34725/TCS34725.h"
#include "lcd1602_display/lcd1602.h"
#include "lcd1602_display/lcd1602_manager.h"
#include "state_machine/state_machine.h"
#include "led/led.h"

/** @brief Global Event Bits Variable für Event Handling */
Event_t eventBits = 0;

/**
 * @brief Initialisiert alle GPIO Ports.
 *
 * Setzt alle GPIO Ports in einen definierten Ausgangszustand:
 *   - Alle Pins als Ausgänge konfiguriert
 *   - Alle Ausgänge auf Low-Pegel gesetzt
 */
void init_all_ports(void)
{
    P1OUT = 0x00;
    P1DIR = 0xFF;
    P2OUT = 0x00;
    P2DIR = 0xFF;
    P3OUT = 0x00;
    P3DIR = 0xFF;
    P4OUT = 0x00;
    P4DIR = 0xFF;
    P5OUT = 0x00;
    P5DIR = 0xFF;
    P6OUT = 0x00;
    P6DIR = 0xFF;

    PAOUT = 0x00;
    PADIR = 0xFF;
    PBOUT = 0x00;
    PBDIR = 0xFF;
    PCOUT = 0x00;
    PCDIR = 0xFF;
}

/**
 * @brief Initialisiert alle Hardwaremodule der Sortieranlage.
 *
 * Führt die Initialisierung in folgender Reihenfolge durch:
 *   1. GPIO Ports (Grundkonfiguration)
 *   2. I2C Bus für Peripherie
 *   3. PCA9685 Servo Controller
 *   4. Timer für Systemtakt
 *   5. TCS34725 Farbsensor
 *   6. Buttons für Benutzereingaben
 *   7. LCD1602 Display
 *   8. Status LEDs
 *
 * Konfiguriert anschließend den 1sek Systemtakt und
 * versetzt die Plattform in die Schlaf Position.
 */
void init(void)
{
    init_all_ports();

    I2C_init();
    PCA9685_init();
    timer_init();
    TCS_init();
    button_init();
    lcd1602_init();
    led_init();

    timer_systick_init(1000);

    plattform_sleep_position();
    turnDisplayOff();

    __enable_interrupt();
}

/**
 * @brief Main Loop
 *
 *   1. Deaktiviert den Watchdog Timer
 *   2. Aktiviert die GPIOs
 *   3. Initialisiert alle Hardwaremodule
 *   4. Verarbeitet Events in main loop mit LPM3
 *
 * Die Main Loop prüft kontinuierlich auf neue Events und
 * leitet diese an die State Machine weiter. In Phasen ohne
 * Events wird der Prozessor in den LPM3 versetzt.
 *
 * @return Wird nie erreicht (Endlosschleife)
 */
int main(void)
{
    State_t currentState = OFF_STATE;
    Event_t event = EVT_NO_EVENT;

    WDTCTL = WDTPW | WDTHOLD;
    PM5CTL0 &= ~LOCKLPM5;

    init();

    while (true)
    {
        event = getEvent(&eventBits);
        if (event != EVT_NO_EVENT)
        {
            while (event > EVT_NO_EVENT)
            {
                handleEvent_FSM(&currentState, event);
                event = getEvent(&eventBits);
            }
        }
        LPM3;
    }
}

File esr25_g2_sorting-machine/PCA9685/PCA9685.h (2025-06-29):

/* ========================================================================== */
/* PCA9685.h                                                                  */
/* ========================================================================== */
/**
 * @file      PCA9685.h
 * @author    wehrberger
 * @date      31.05.2025
 *
 * @brief     PCA9685 16-Kanal PWM-Treiber für Servo- und LED-Steuerung.
 *
 * Dieses Modul bietet eine einfache Schnittstelle zum PCA9685 16-Kanal
 * 12-Bit PWM-Treiber über I²C-Kommunikation. Der Treiber bietet grundlegende
 * Funktionalität für:
 *   - PCA9685_init()                – Initialisierung für 50 Hz PWM-Betrieb
 *   - PCA9685_set_servo_position()  – PWM-Position für Servo-Steuerung setzen
 *
 * Der Treiber ist optimiert für Servo-Anwendungen mit 50 Hz PWM-Frequenz
 * und bietet vordefinierte Konstanten für die Kippplatform.
 *
 * @note Dieser Treiber benötigt eine funktionsfähige I²C-Schnittstelle.
 *       Vor Verwendung anderer Funktionen muss die init() Methode aufgerufen werden.
 */

#ifndef PCA9685_H
#define PCA9685_H

#include <stdint.h>

/* ========================================================================== */
/* Konstanten                                           */
/* ========================================================================== */

/** @brief I²C-Slave-Adresse des PCA9685-Moduls. */
#define PCA9685_ADDR      0x40

/* ========================================================================== */
/* PCA9685 Registeradressen                                                   */
/* ========================================================================== */

/** @brief LED0_ON_L Register – Kanal 0 Ein-Zeit Low-Byte. */
#define LED0_ON_L         0x06

/** @brief LED0_ON_H Register – Kanal 0 Ein-Zeit High-Byte. */
#define LED0_ON_H         0x07

/** @brief LED0_OFF_L Register – Kanal 0 Aus-Zeit Low-Byte. */
#define LED0_OFF_L        0x08

/** @brief LED0_OFF_H Register – Kanal 0 Aus-Zeit High-Byte. */
#define LED0_OFF_H        0x09

/* ========================================================================== */
/* Register makros                                                 */
/* ========================================================================== */

/** @brief Berechnet LED_ON_L Registeradresse für gegebenen Kanal. */
#define LED_ON_L(channel)  (LED0_ON_L + 4 * (channel))

/** @brief Berechnet LED_ON_H Registeradresse für gegebenen Kanal. */
#define LED_ON_H(channel)  (LED0_ON_H + 4 * (channel))

/** @brief Berechnet LED_OFF_L Registeradresse für gegebenen Kanal. */
#define LED_OFF_L(channel) (LED0_OFF_L + 4 * (channel))

/** @brief Berechnet LED_OFF_H Registeradresse für gegebenen Kanal. */
#define LED_OFF_H(channel) (LED0_OFF_H + 4 * (channel))

/* ========================================================================== */
/* Servo-Positionskonstanten                                                  */
/* ========================================================================== */

/** Konstanten sind optimiert für die Kippplattform */

/** @brief PWM-Wert für 40° Servo-Position  (≈ 1.20 ms Pulsweite). */
#define SERVO_DEG_PULSE_40   240

/** @brief PWM-Wert für 50° Servo-Position  (≈ 1.30 ms Pulsweite). */
#define SERVO_DEG_PULSE_50   265

/** @brief PWM-Wert für 60° Servo-Position  (≈ 1.41 ms Pulsweite). */
#define SERVO_DEG_PULSE_60   290

/** @brief PWM-Wert für 90° Servo-Position  (≈ 1.78 ms Pulsweite). */
#define SERVO_DEG_PULSE_90   365

/** @brief PWM-Wert für 120° Servo-Position (≈ 2.15 ms Pulsweite). */
#define SERVO_DEG_PULSE_120  440

/** @brief PWM-Wert für 135° Servo-Position (≈ 2.33 ms Pulsweite). */
#define SERVO_DEG_PULSE_135  477

/**
 * @brief Initialisiert den PCA9685 für 50 Hz PWM-Betrieb.
 *
 * Konfiguriert den PCA9685 mit folgenden Einstellungen:
 *   - PWM-Frequenz: 50 Hz (geeignet für Standard-Servos)
 *   - PRESCALE: 121 (0x79) für 25 MHz Oszillator
 *   - Auto-Increment und ALLCALL aktiviert
 *
 * @note Der PCA9685 wird kurzzeitig in den SLEEP-Modus versetzt,
 *       um den PRESCALE-Wert zu setzen.
 */
void PCA9685_init(void);

/**
 * @brief Setzt die PWM-Position eines bestimmten Kanals.
 *
 * Konfiguriert die PWM-Ausgabe für einen spezifischen Kanal.
 * Das PWM-Signal startet immer bei 0 (LED_ON = 0) und endet
 * bei der angegebenen Position (LED_OFF = position).
 *
 * @param[in] channel Kanal-Nummer (0-15). Werte außerhalb dieses
 *                    Bereichs werden ignoriert.
 * @param[in] position 12-Bit PWM-Position (0-4095). Bestimmt die
 *                     Pulsweite des PWM-Signals.
 */
void PCA9685_set_servo_position(uint8_t channel, uint16_t position);

#endif /* PCA9685_H */

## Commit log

2025-05-31 Add I2C driver implementation: - Implements init_I2C, write_I2C, and read_I2C functions - Uses interrupt-driven transmission via EUSCI_B0 ISR
2025-05-31 Add PCA9685 Communication implementation - Defines LED ON/OFF register macros for all 16 channels - Sets default pulse width range (145–605) for 0–180° mapping - Adds PCA9685 I2C address and base reg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
2025-05-31 Add main implementation for turning servo - inits I2C - inits the PCA - added delay helpers temporarliy - unlock all GPIOS - turns servo at channel 0 between 0 and 180 deg with 2 sec delay between - 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
2025-05-31 fix wrong I2C.h import
    [I2C.c]
2025-06-10 add servo control api
2025-06-10 update I2C api
2025-06-10 Read Methode Sensor
2025-06-10 refactor servo control
2025-06-10 add timer module - add timer_init function - add timer_sleep_ms
2025-06-13 added driver lib and lcd functionality
2025-06-14 finished feature test, now requires verdrahtungsplan and rework based on our implementations.
    [main.c]
2025-06-17 add: I2C doxygen comments
2025-06-17 add: doxygen timer module
2025-06-20 add: wirediagram into assets
2025-06-20 update: doxygen comments for I2C
2025-06-20 update: doxygen comments for timer modul
2025-06-22 Added button functionality to activate the display and test each of my functions. Implemented every function that is required to display the needed information: ShowReady(), ShowCurrentCount(), showD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
2025-06-22 deleted LED functionality, and cleaned up
2025-06-23 first basic implementation of the finite state machine. Open tasks: Move the button stuff in an extra folder, Discuss events and I2C-Communication.
2025-06-26 remove: driverlib
2025-06-27 refactor: I2C wake up
2025-06-27 add: timer bool against early wake ups by other ISRs
2025-06-28 button debounce
2025-06-29 add: button doxygen comments
2025-06-29 add: defines for servo type
2025-06-29 add: led statusanzeige
2025-06-29 refactor: docs gen
    [wire_diagram_3.fzz]
2025-06-29 refactor: folder structure
    [wire_diagram_3.fzz]
